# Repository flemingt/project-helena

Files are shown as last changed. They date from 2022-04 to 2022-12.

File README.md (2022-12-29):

# project-helena
Atari XL keyboard replacement

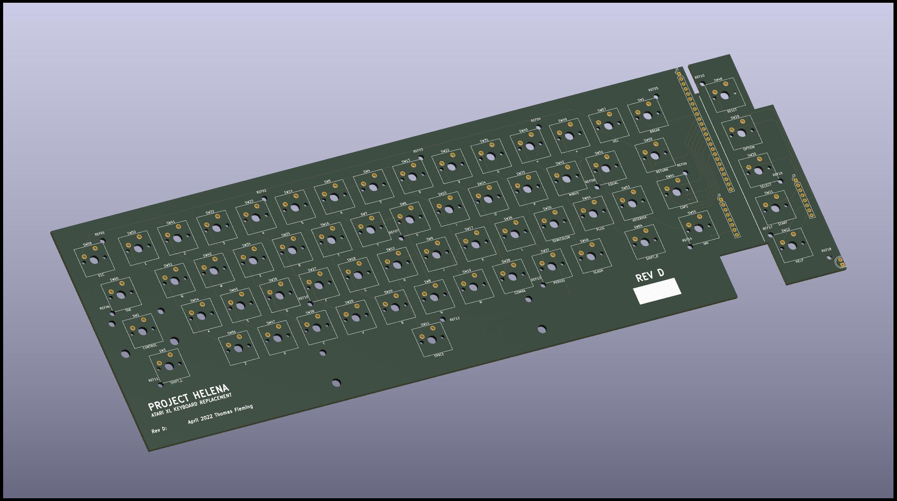
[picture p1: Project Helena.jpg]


What can go wrong with a bunch of switches? :)

Building on Ivop's project I've designed rev B, C, & D of the board.
Rev D has been designed with slightly different ribbon cable mounting points and moved the LED solder location to shorten the length of the board by a few mm. It is now ~111x346mm

The Helena Aux pcb plugs into the keyboard ribbon slot on the mainboard. For the 600XL 0.8mm seems to work, but 0.6mm or thinner is required for the 800XL.

I've added holes to make the switches PCB mount, some holes to mount stabilisers for the spacebar, and even more holes to align with the metal backplane of the original mylar / Stackpole keyboard of my 600XL. Maybe someone will need the mounting holes in the future. 

I've designed some 3D printed bracketry to use the screw posts in the top half of the case. Also some upper supports to minimise keyboard flex. These hook on to the PCB and the aluminium pieces that hold the cartridge doors.

I've designed cherry to Stackpole replacement stems for mechanical switches, but in the end I went for adaptors.

In addition, I've created a bracket to mount the U1MB expansion board. Note, you'll have to relocate the battery to make this all fit in the confines of a 600XL.

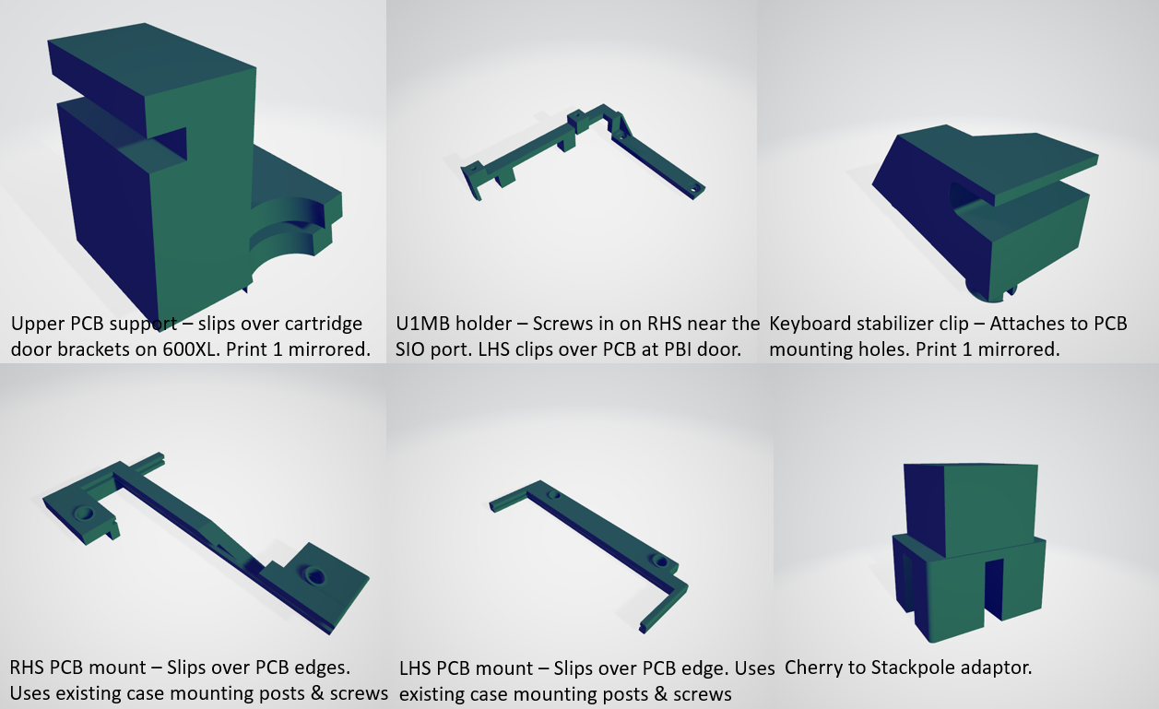
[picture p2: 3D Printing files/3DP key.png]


All the 3D printed parts use standard PLA, 50% infill. Some of the shapes area a bit tricky, but I've successfully printed everything with some thought on orientation and supports in the slicer.

Scorpio_NY on the Atariage forums has created 3D printable plates which will stiffen up the keyboard PCB and allow more accurate mounting on the switches. See the "Plate Files" directory. To accomodate the plates he's also developed new stabilizer files (in the "Final Stab Files" directory) and support brackets (in the "Final Support Bracket Files" directory).

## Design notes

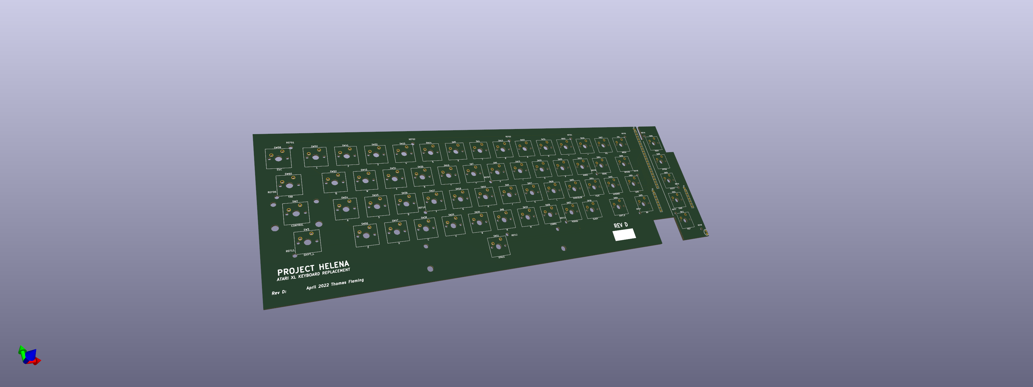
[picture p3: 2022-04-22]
kicad/Helena Main/Raytraced.png

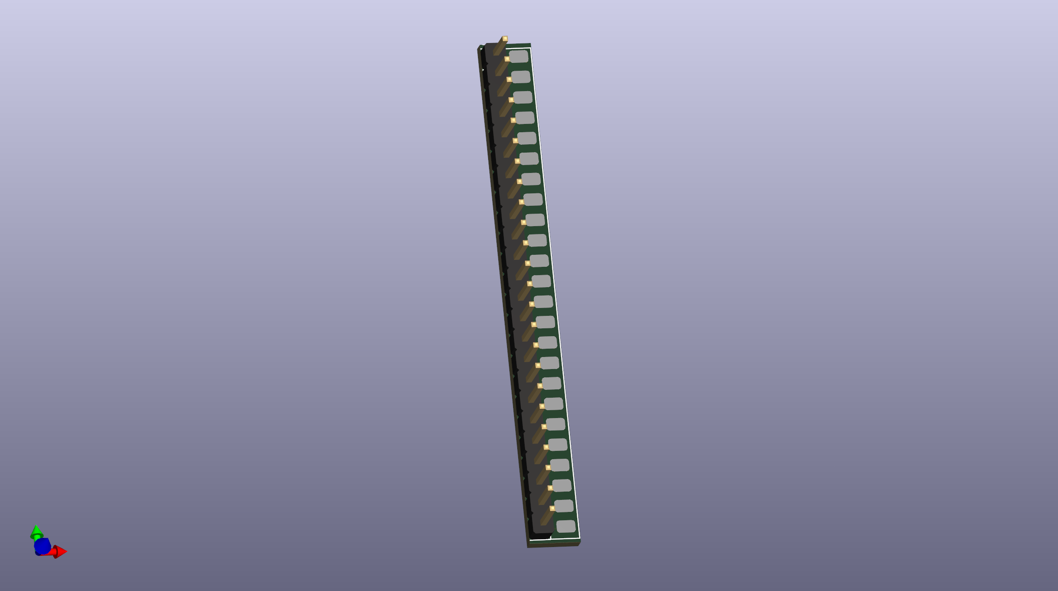
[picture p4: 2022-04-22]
kicad/Helena Aux/Raytraced.png

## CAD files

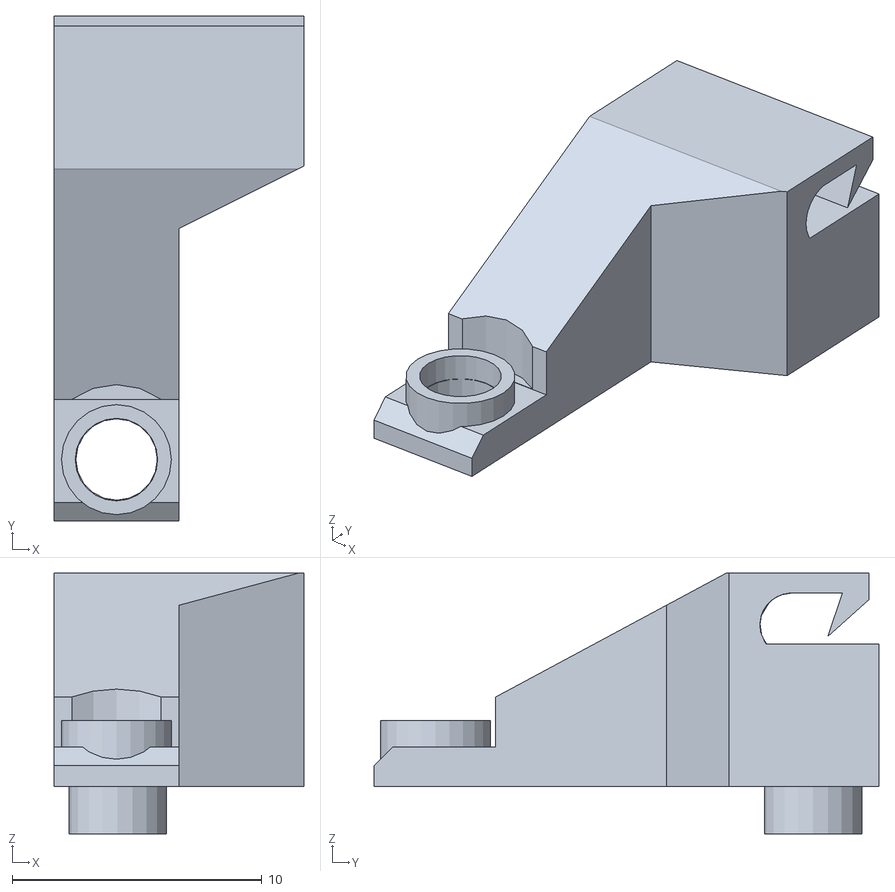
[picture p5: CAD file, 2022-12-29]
3D Printing files/Final Stab Files/PH Right Stab V 1.0 Final.stl
10.0 x 20.2 x 10.4

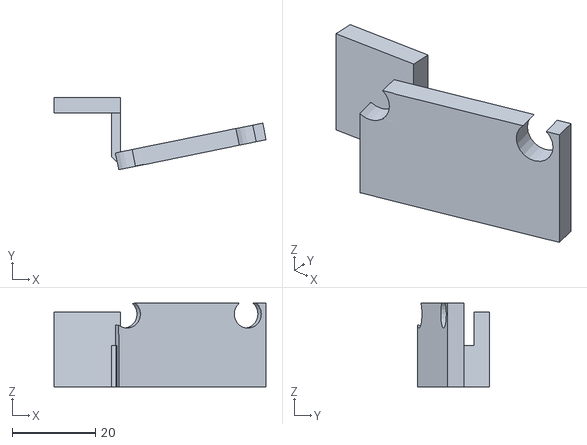
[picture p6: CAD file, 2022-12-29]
3D Printing files/Final Support Bracket Files/600XL/Project Helena 600XL Support Right v 1.0.stl
51.0 x 17.4 x 20.1

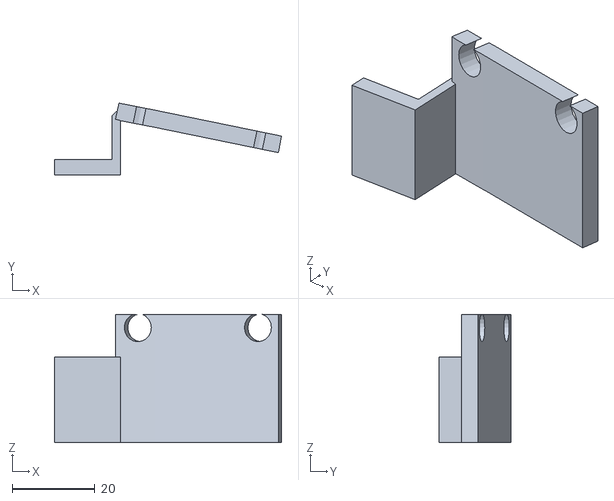
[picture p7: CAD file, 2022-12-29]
3D Printing files/Final Support Bracket Files/800XL/Project Helena Support 800XL Back Right v 1.0 (meshmixer).stl
54.9 x 17.4 x 31.0

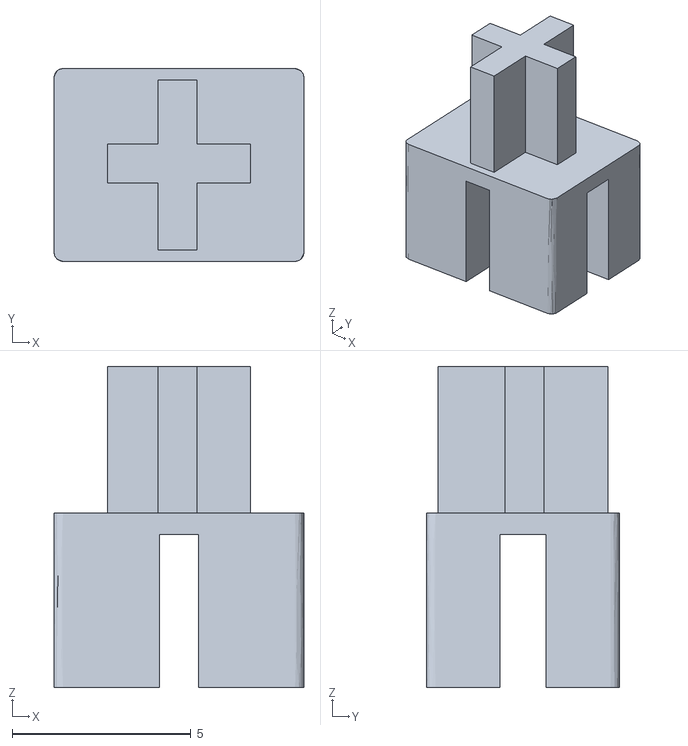
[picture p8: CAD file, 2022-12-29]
3D Printing files/MX to Futaba Final 1.0.stl
7.00 x 5.40 x 8.99

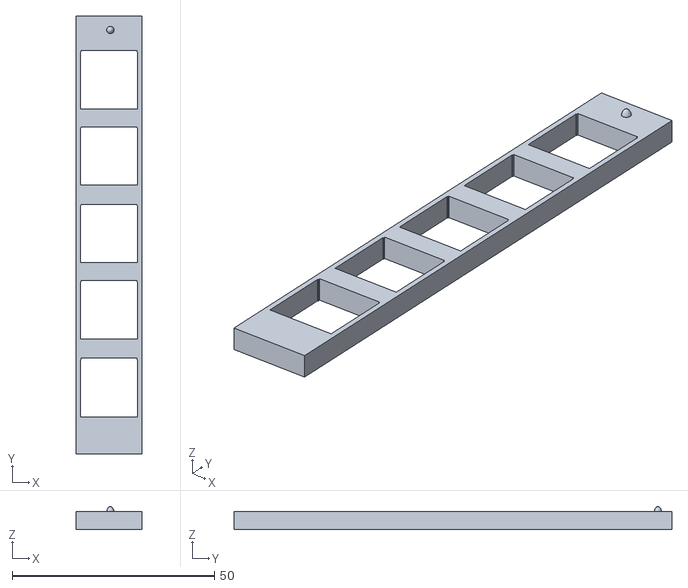
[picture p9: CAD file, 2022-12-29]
3D Printing files/Plate Files 1.0/Project Helena PCB_M.svg_4.5mm Function Keys v 1.0.stl
16.3 x 108.4 x 5.70

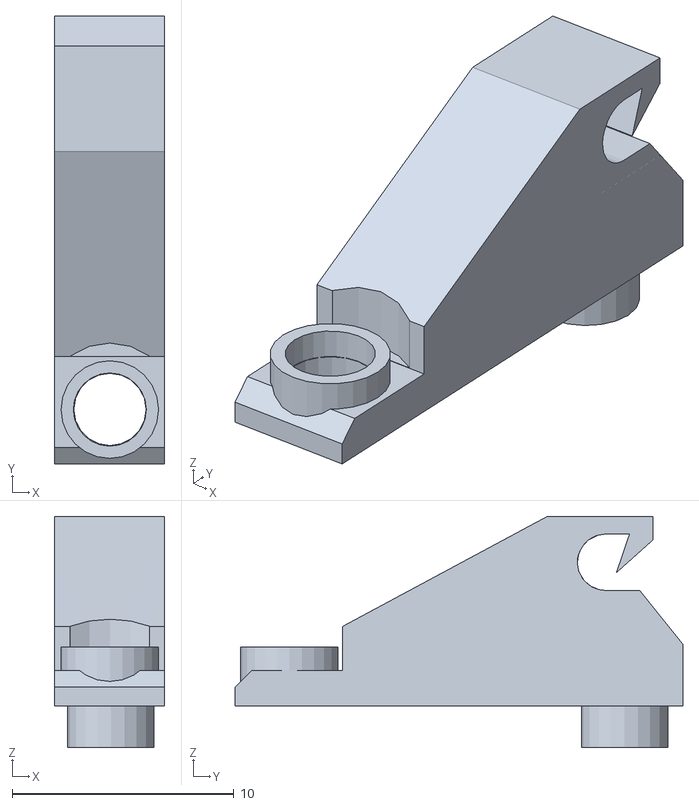
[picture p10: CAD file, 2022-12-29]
3D Printing files/Final Stab Files/Small Stab v 1.0.stl
4.97 x 20.2 x 10.4

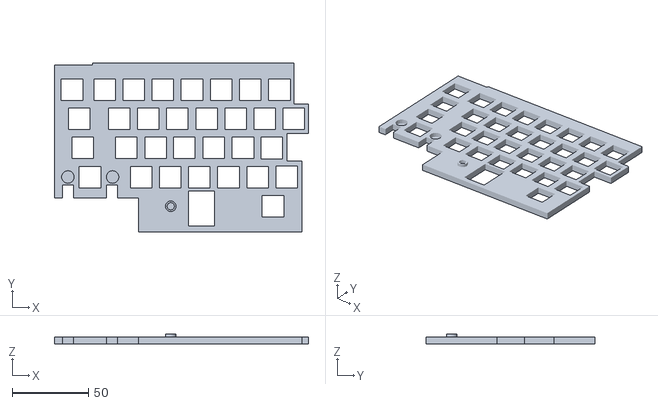
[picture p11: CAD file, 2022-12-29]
3D Printing files/Plate Files 1.0/Project Helena PCB_M.svg_4.5mm Left Half v 1.0 Final.stl
166.2 x 110.4 x 6.50

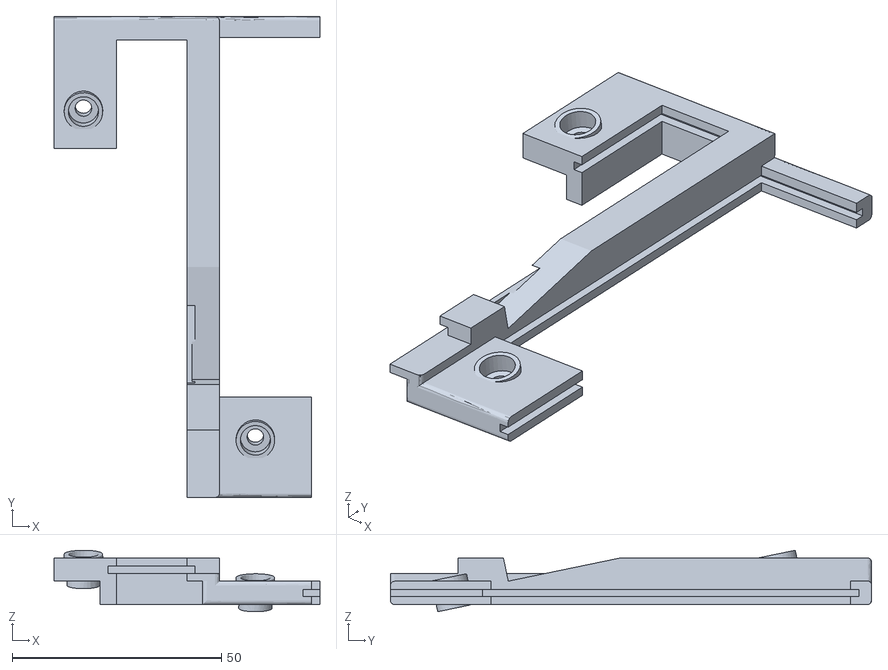
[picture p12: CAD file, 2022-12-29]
3D Printing files/RHS Final 800XL Remix.stl
63.5 x 115.0 x 14.7

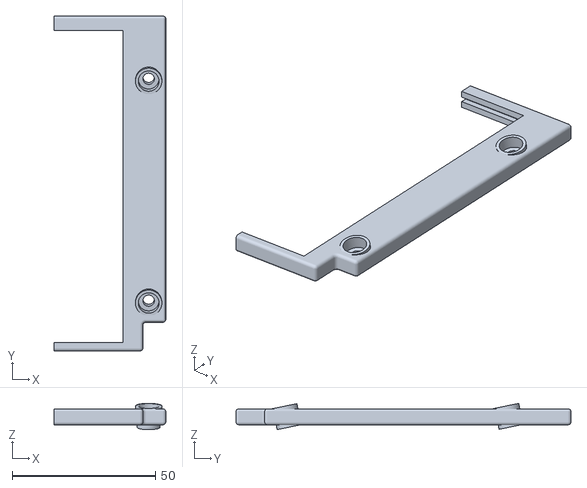
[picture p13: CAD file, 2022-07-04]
3D Printing files/LHS Final.stl
39.0 x 117.0 x 9.19

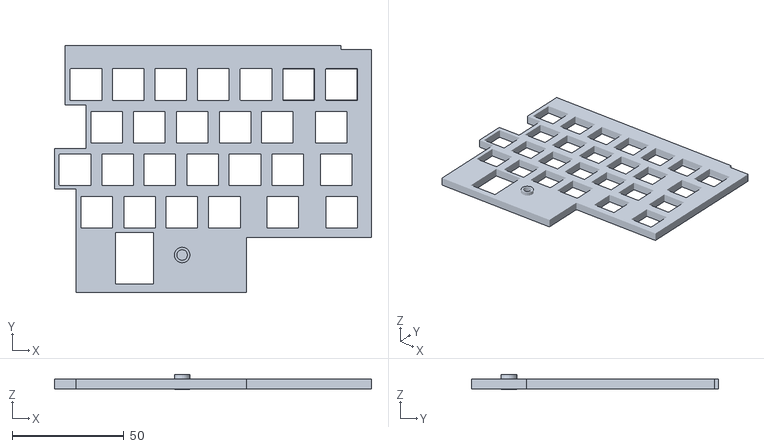
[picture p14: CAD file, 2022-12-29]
3D Printing files/Plate Files 1.0/Project Helena PCB_M.svg_4.5mm Right Half v 1.0 Final.stl
141.7 x 110.4 x 6.50

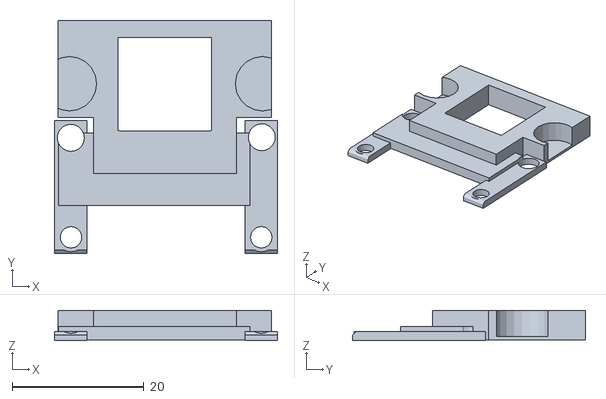
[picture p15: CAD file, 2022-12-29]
3D Printing files/Final Stab Files/Stab Hole Template v 1.0.stl
33.8 x 35.3 x 4.59

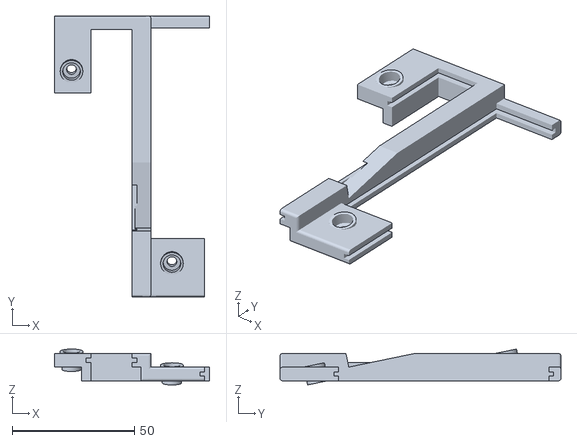
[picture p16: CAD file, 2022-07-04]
3D Printing files/RHS Final.stl
63.5 x 115.0 x 14.7

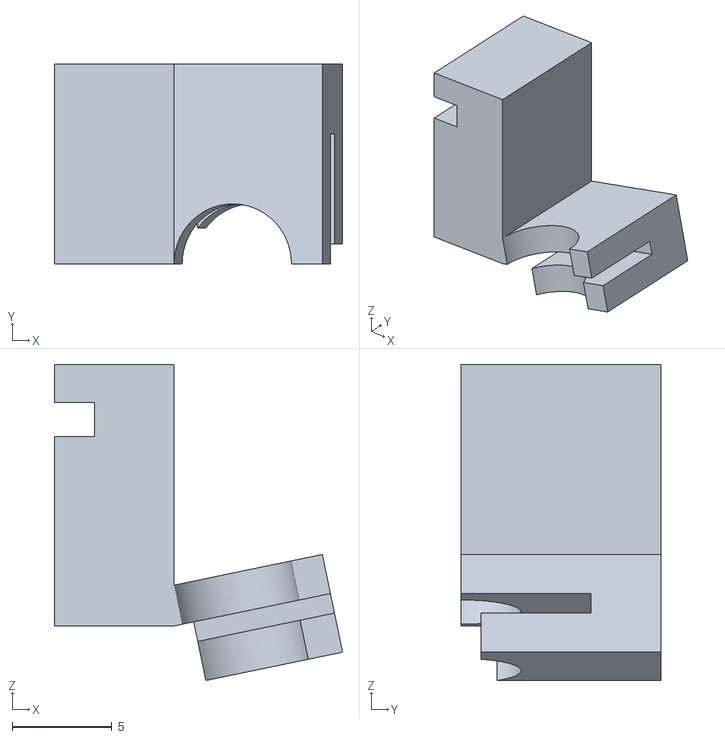
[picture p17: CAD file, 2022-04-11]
3D Printing files/upper support final.stl
14.4 x 10.0 x 15.8

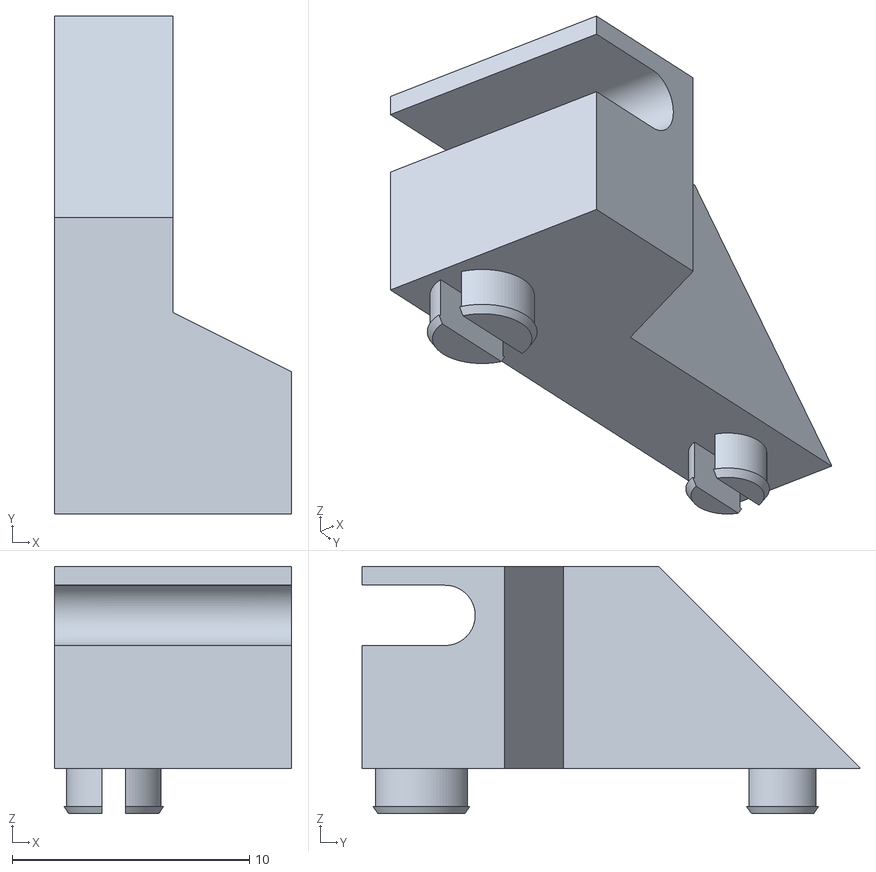
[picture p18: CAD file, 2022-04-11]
3D Printing files/Stab Final.stl
10.0 x 21.0 x 10.4

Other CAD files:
3D Printing files/Final Support Bracket Files/600XL/Project Helena 600XL Support Left v 1.0.stl
3D Printing files/Final Stab Files/PH Left Stab V.1.0 Final.stl
3D Printing files/U1MB near final.stl
3D Printing files/Cherry to stackpole Final.stl

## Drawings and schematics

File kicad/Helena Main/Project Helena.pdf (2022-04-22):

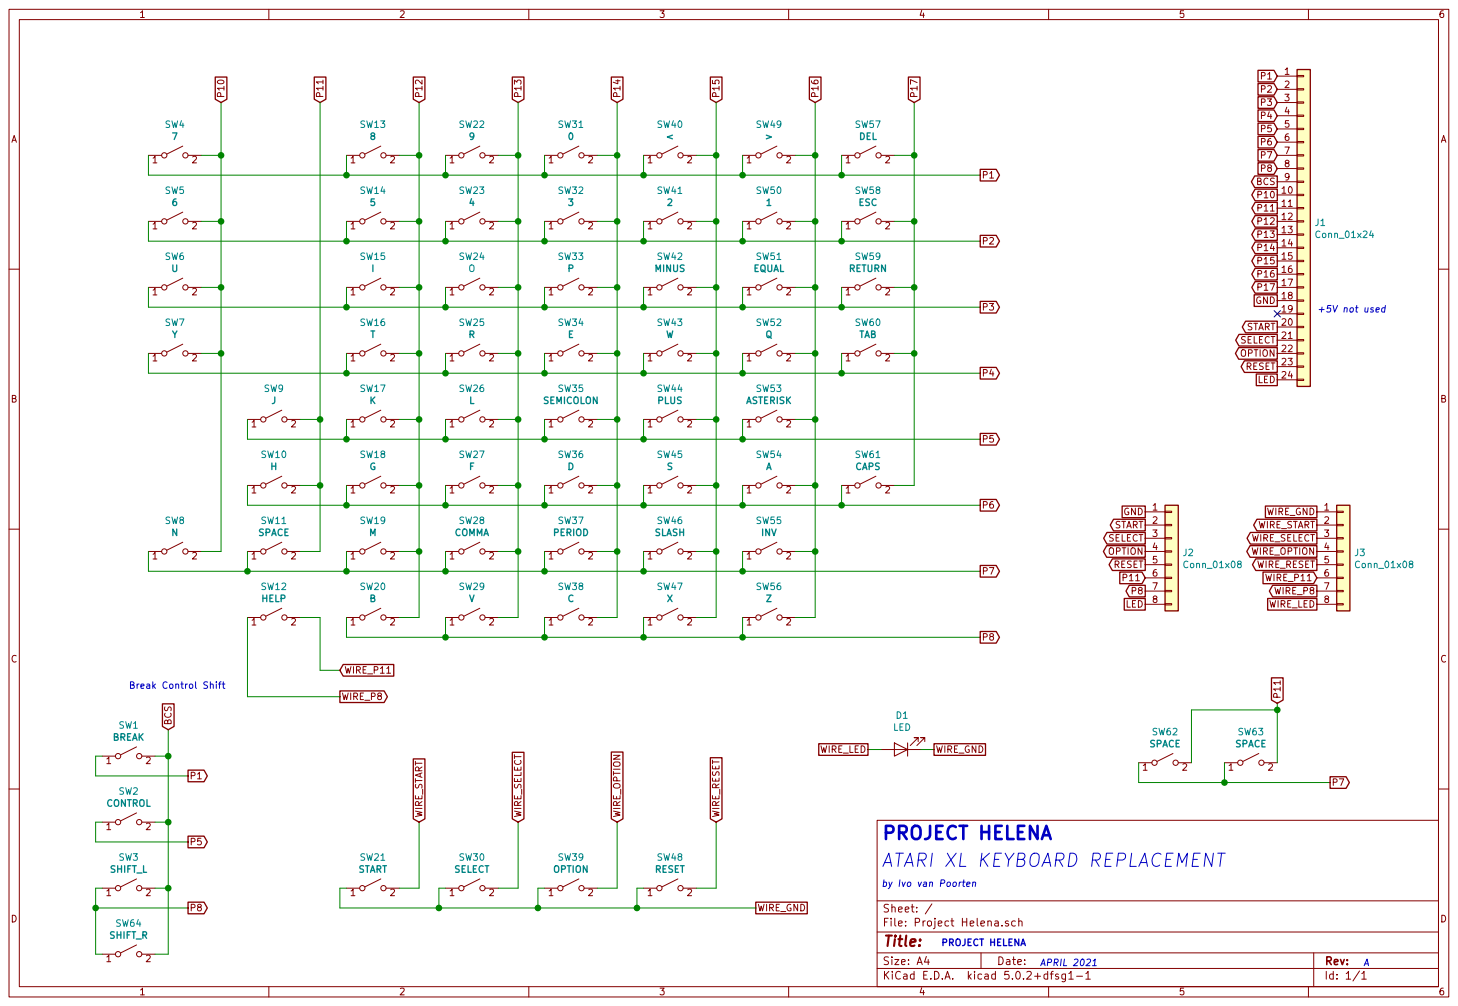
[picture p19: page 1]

+5V not used PROJECT HELENA

ATARI XL KEYBOARD REPLACEMENT

by Ivo van Poorten PROJECT HELENA

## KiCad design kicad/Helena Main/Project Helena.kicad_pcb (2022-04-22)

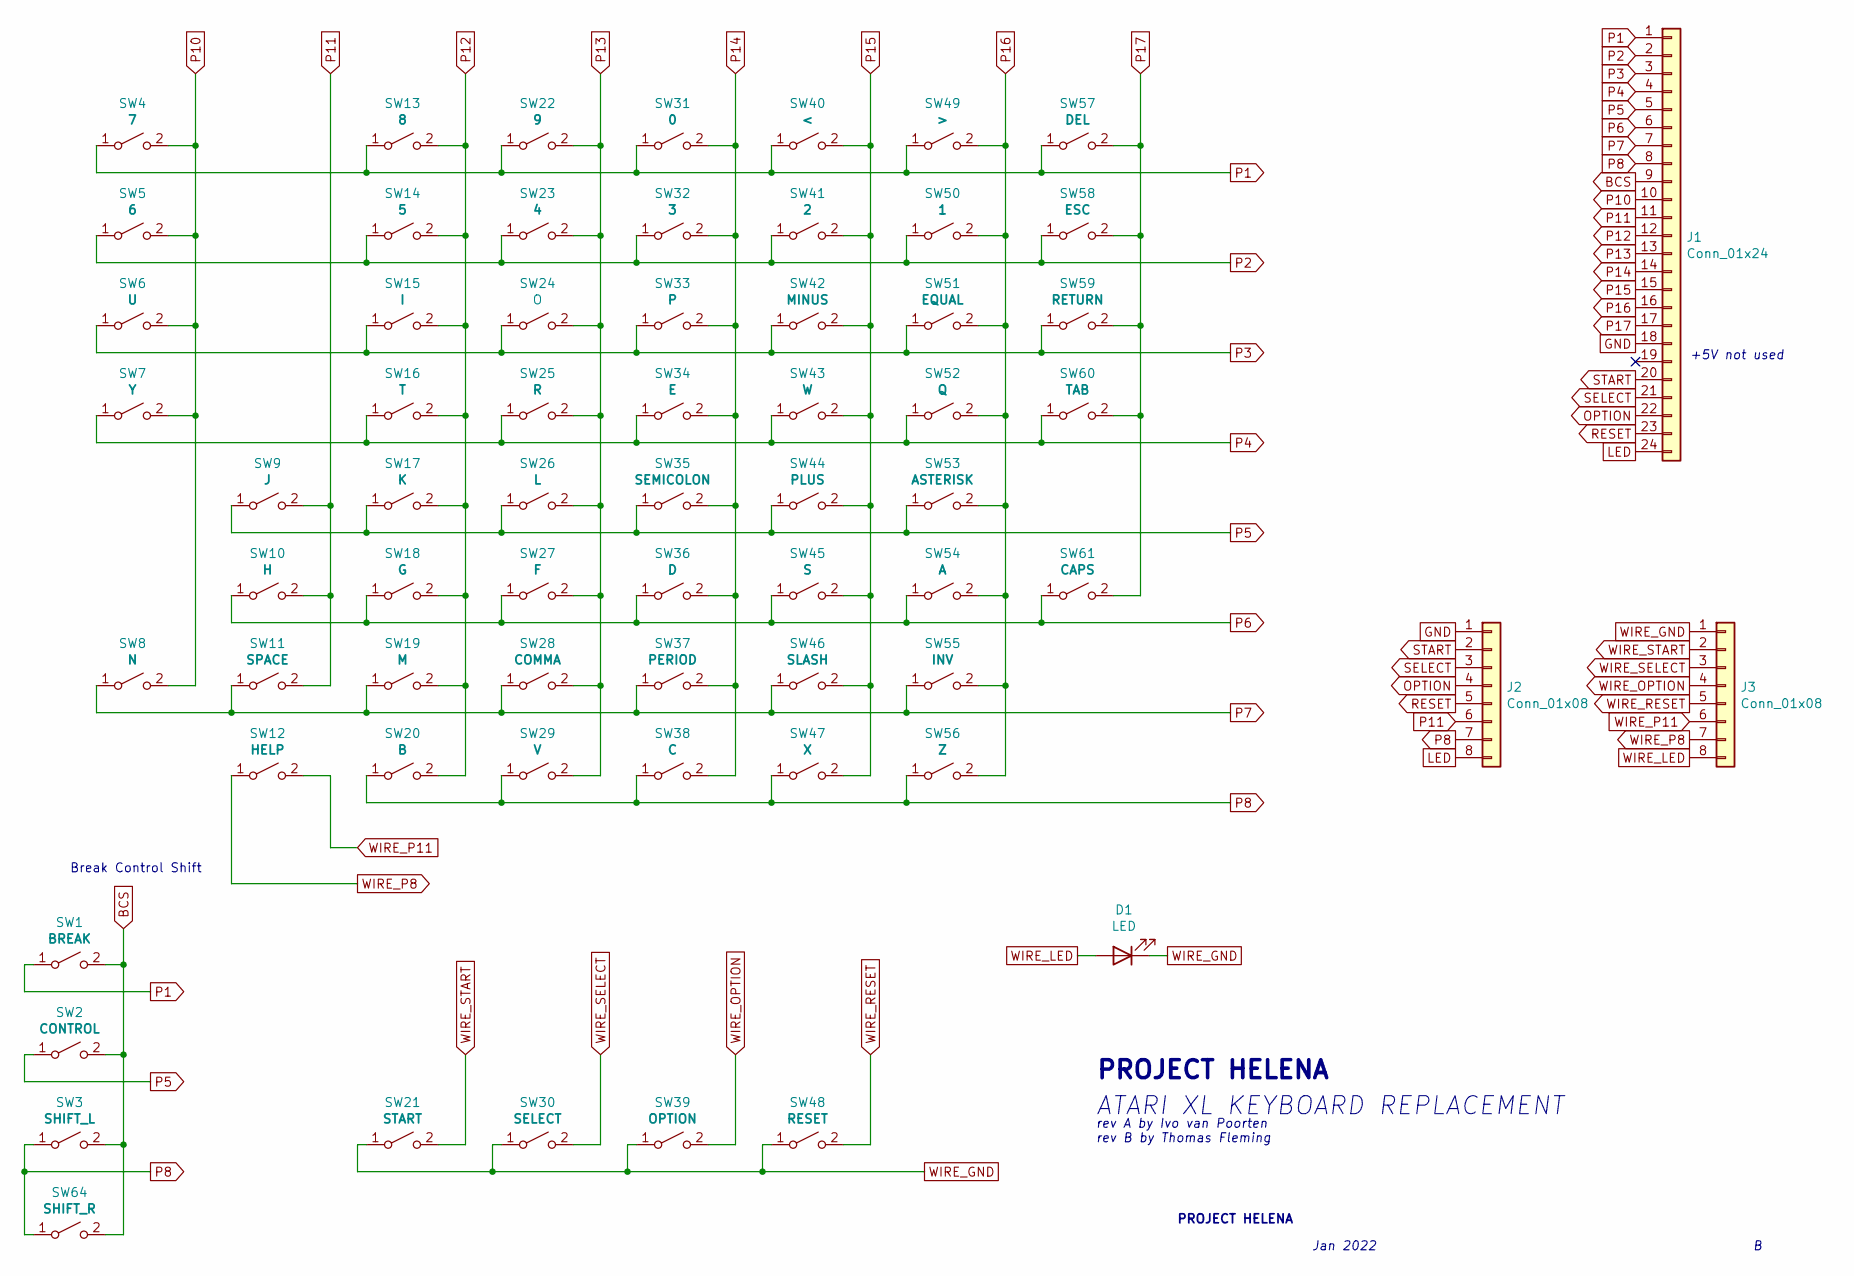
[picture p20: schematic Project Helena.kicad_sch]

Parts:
D1: LED; LED_D5.0mm
J1: Conn_01x24; PinHeader_1x24_P2.54mm_Vertical
J2, J3: Conn_01x08; PinHeader_1x08_P2.54mm_Vertical
SW1: BREAK; SW_Cherry_MX1A_1.00u_Plate
SW2: CONTROL; SW_Cherry_MX1A_2.00u_Plate
SW3: SHIFT_L; SW_Cherry_MX1A_1.50u_Plate
SW4: 7; SW_Cherry_MX1A_1.00u_Plate
SW5: 6; SW_Cherry_MX1A_1.00u_Plate
SW6: U; SW_Cherry_MX1A_1.00u_Plate
SW7: Y; SW_Cherry_MX1A_1.00u_Plate
SW8: N; SW_Cherry_MX1A_1.00u_Plate
SW9: J; SW_Cherry_MX1A_1.00u_Plate
SW10: H; SW_Cherry_MX1A_1.00u_Plate
SW11: SPACE; SW_Cherry_MX1A_1.00u_Plate
SW12: HELP; SW_Cherry_MX1A_1.00u_Plate
SW13: 8; SW_Cherry_MX1A_1.00u_Plate
SW14: 5; SW_Cherry_MX1A_1.00u_Plate
SW15: I; SW_Cherry_MX1A_1.00u_Plate
SW16: T; SW_Cherry_MX1A_1.00u_Plate
SW17: K; SW_Cherry_MX1A_1.00u_Plate
SW18: G; SW_Cherry_MX1A_1.00u_Plate
SW19: M; SW_Cherry_MX1A_1.00u_Plate
SW20: B; SW_Cherry_MX1A_1.00u_Plate
SW21: START; SW_Cherry_MX1A_1.00u_Plate
SW22: 9; SW_Cherry_MX1A_1.00u_Plate
SW23: 4; SW_Cherry_MX1A_1.00u_Plate
SW24: O; SW_Cherry_MX1A_1.00u_Plate
SW25: R; SW_Cherry_MX1A_1.00u_Plate
SW26: L; SW_Cherry_MX1A_1.00u_Plate
SW27: F; SW_Cherry_MX1A_1.00u_Plate
SW28: COMMA; SW_Cherry_MX1A_1.00u_Plate
SW29: V; SW_Cherry_MX1A_1.00u_Plate
SW30: SELECT; SW_Cherry_MX1A_1.00u_Plate
SW31: 0; SW_Cherry_MX1A_1.00u_Plate
SW32: 3; SW_Cherry_MX1A_1.00u_Plate
SW33: P; SW_Cherry_MX1A_1.00u_Plate
SW34: E; SW_Cherry_MX1A_1.00u_Plate
SW35: SEMICOLON; SW_Cherry_MX1A_1.00u_Plate
SW36: D; SW_Cherry_MX1A_1.00u_Plate
SW37: PERIOD; SW_Cherry_MX1A_1.00u_Plate
SW38: C; SW_Cherry_MX1A_1.00u_Plate
SW39: OPTION; SW_Cherry_MX1A_1.00u_Plate
SW40: <; SW_Cherry_MX1A_1.00u_Plate
SW41: 2; SW_Cherry_MX1A_1.00u_Plate
SW42: MINUS; SW_Cherry_MX1A_1.00u_Plate
SW43: W; SW_Cherry_MX1A_1.00u_Plate
SW44: PLUS; SW_Cherry_MX1A_1.00u_Plate
SW45: S; SW_Cherry_MX1A_1.00u_Plate
SW46: SLASH; SW_Cherry_MX1A_1.00u_Plate
SW47: X; SW_Cherry_MX1A_1.00u_Plate
SW48: RESET; SW_Cherry_MX1A_1.00u_Plate
SW49: >; SW_Cherry_MX1A_1.00u_Plate
SW50: 1; SW_Cherry_MX1A_1.00u_Plate
SW51: EQUAL; SW_Cherry_MX1A_1.00u_Plate
SW52: Q; SW_Cherry_MX1A_1.00u_Plate
SW53: ASTERISK; SW_Cherry_MX1A_1.00u_Plate
SW54: A; SW_Cherry_MX1A_1.00u_Plate
SW55: INV; SW_Cherry_MX1A_1.00u_Plate
SW56: Z; SW_Cherry_MX1A_1.00u_Plate
SW57: DEL; SW_Cherry_MX1A_1.00u_Plate
SW58: ESC; SW_Cherry_MX1A_1.25u_Plate
SW59: RETURN; SW_Cherry_MX1A_1.50u_Plate
SW60: TAB; SW_Cherry_MX1A_1.75u_Plate
SW61: CAPS; SW_Cherry_MX1A_1.25u_Plate
SW64: SHIFT_R; SW_Cherry_MX1A_1.75u_Plate

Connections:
BCS: J1.9, SW1.2 (B), SW2.2 (B), SW3.2 (B), SW64.2 (B)
GND: J1.18, J2.1
LED: J1.24, J2.8
OPTION: J1.22, J2.4
P1: J1.1, SW1.1 (A), SW4.1 (A), SW13.1 (A), SW22.1 (A), SW31.1 (A), SW40.1 (A), SW49.1 (A), SW57.1 (A)
P2: J1.2, SW5.1 (A), SW14.1 (A), SW23.1 (A), SW32.1 (A), SW41.1 (A), SW50.1 (A), SW58.1 (A)
P3: J1.3, SW6.1 (A), SW15.1 (A), SW24.1 (A), SW33.1 (A), SW42.1 (A), SW51.1 (A), SW59.1 (A)
P4: J1.4, SW7.1 (A), SW16.1 (A), SW25.1 (A), SW34.1 (A), SW43.1 (A), SW52.1 (A), SW60.1 (A)
P5: J1.5, SW2.1 (A), SW9.1 (A), SW17.1 (A), SW26.1 (A), SW35.1 (A), SW44.1 (A), SW53.1 (A)
P6: J1.6, SW10.1 (A), SW18.1 (A), SW27.1 (A), SW36.1 (A), SW45.1 (A), SW54.1 (A), SW61.1 (A)
P7: J1.7, SW8.1 (A), SW11.1 (A), SW19.1 (A), SW28.1 (A), SW37.1 (A), SW46.1 (A), SW55.1 (A)
P8: J1.8, J2.7, SW3.1 (A), SW20.1 (A), SW29.1 (A), SW38.1 (A), SW47.1 (A), SW56.1 (A), SW64.1 (A)
P10: J1.10, SW4.2 (B), SW5.2 (B), SW6.2 (B), SW7.2 (B), SW8.2 (B)
P11: J1.11, J2.6, SW9.2 (B), SW10.2 (B), SW11.2 (B)
P12: J1.12, SW13.2 (B), SW14.2 (B), SW15.2 (B), SW16.2 (B), SW17.2 (B), SW18.2 (B), SW19.2 (B), SW20.2 (B)
P13: J1.13, SW22.2 (B), SW23.2 (B), SW24.2 (B), SW25.2 (B), SW26.2 (B), SW27.2 (B), SW28.2 (B), SW29.2 (B)
P14: J1.14, SW31.2 (B), SW32.2 (B), SW33.2 (B), SW34.2 (B), SW35.2 (B), SW36.2 (B), SW37.2 (B), SW38.2 (B)
P15: J1.15, SW40.2 (B), SW41.2 (B), SW42.2 (B), SW43.2 (B), SW44.2 (B), SW45.2 (B), SW46.2 (B), SW47.2 (B)
P16: J1.16, SW49.2 (B), SW50.2 (B), SW51.2 (B), SW52.2 (B), SW53.2 (B), SW54.2 (B), SW55.2 (B), SW56.2 (B)
P17: J1.17, SW57.2 (B), SW58.2 (B), SW59.2 (B), SW60.2 (B), SW61.2 (B)
RESET: J1.23, J2.5
SELECT: J1.21, J2.3
START: J1.20, J2.2
WIRE_GND: D1.1 (K), J3.1, SW21.1 (A), SW30.1 (A), SW39.1 (A), SW48.1 (A)
WIRE_LED: D1.2 (A), J3.8
WIRE_OPTION: J3.4, SW39.2 (B)
WIRE_P8: J3.7, SW12.1 (A)
WIRE_P11: J3.6, SW12.2 (B)
WIRE_RESET: J3.5, SW48.2 (B)
WIRE_SELECT: J3.3, SW30.2 (B)
WIRE_START: J3.2, SW21.2 (B)

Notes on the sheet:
+5V not used
Break Control Shift
rev A by Ivo van Poorten rev B by Thomas Fleming
ATARI XL KEYBOARD REPLACEMENT
Jan 2022
PROJECT HELENA

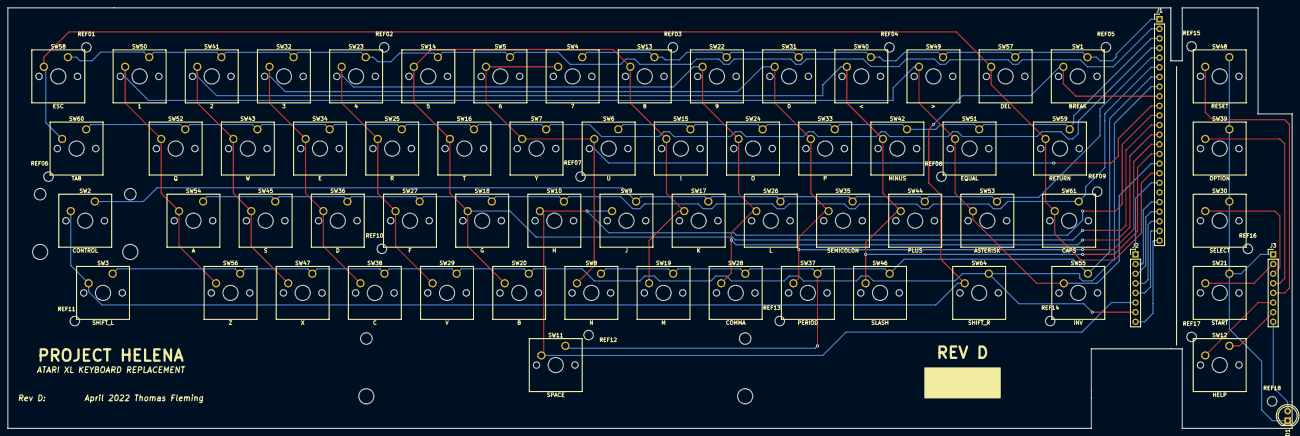
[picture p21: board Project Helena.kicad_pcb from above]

Board: 2 copper layers, 339.0 x 111.0 mm, 84 parts (0 on the bottom side), 31 nets.

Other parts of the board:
REF01, REF02, REF03, REF04, REF05, REF06, REF07, REF08, REF09, REF10, REF11, REF12, REF13, REF14, REF15, REF16, REF17, REF18: MountingHole_2.5mm

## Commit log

2022-01-27 Created Rev B
    Rev B of ivops Atari600xl keyboard.
    Modified switch footprints to accommodate 5 holes for stability.
    Added PCB mount stabilizer holes for 3D printed brackets.
    Added through-holes to match the metal backplate on my membrane 600xl keyboard with the intention of making stand-offs.
    Extensively rerouted traces to avoid all the new holes.
    [Cherry to Stackpool v1.stl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]
2022-01-28 adding 3D printing file/folder
    adding folder for 3D printing and rev 1 of cherry to stackpole stem replacement
    [cherry to stackpole replacement stem.stl]
2022-02-01 cherry / Gateron to stackpole replacement stem v2
    Version 2 with longer Stackpole section to accommodate keypress full travel
    [cherry to stackpole replacement stem v2.stl]
2022-02-02 cherry / Gateron to stackpole replacement stem v3
    Redrew CAD from scratch and added some stabilising features
    [cherry to stackpole replacement stem v3.stl]
2022-02-05 Add files via upload
    raised wings by 0.75mm and narrowed each by 0.5mm
    [cherry to stackpole replacement stem v4.stl]
2022-03-18 Add files via upload
    Updated PCB to rev C. Moved backplane holes for better alignment. Moved main connector to prevent ribbon cable overlap with daughterboard.
    [Project Helena.kicad_pcb]
2022-03-19 Update README.md
    updated to reflect current status of rev C
2022-03-20 Delete cherry to stackpole replacement stem v2.stl
    Version 4 is better
    [cherry to stackpole replacement stem v2.stl]
2022-03-20 Delete cherry to stackpole replacement stem v3.stl
    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
    [cherry to stackpole replacement stem v3.stl]
2022-03-20 Delete cherry to stackpole replacement stem.stl
    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
    [cherry to stackpole replacement stem.stl]
2022-03-20 Left hand side keyboard PCB mount
    [LHS keyboard mount V2.stl]
2022-04-03 Delete LHS keyboard mount V2.stl
    replacing with near final version
    [LHS keyboard mount V2.stl]
2022-04-03 Add files via upload
    near final keyboard mounting brackets. Z may need some tweaking
    [LHS keyboard mount V5.stl, middle keyboard mount V6.stl]
2022-04-03 Add files via upload
    Ultimate 1MB holder designed to go under the new keyboard. Note desolder and relocate the battery.
    [U1MB holder v3.stl]
2022-04-03 Update README.md
    updating to reflect current status.
2022-04-11 Adding near final versions of 3D printable files
    [Cherry to stackpole Final.stl, LHS Final.stl, RHS Final.stl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]
2022-04-22 Delete kicad directory
    preparing for rev D
    [Project Helena-B.Cu.gbr, Project Helena-B.Mask.gbr, Project Helena-B.SilkS.gbr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]
2022-04-22 Add files via upload
    Updating main PCB to rev D: shorter with better placement of power LED.
    Creating rev A of Aux PCB to interface with the existing mylar connector.
    [Helena Aux-B_Cu.gbr, Helena Aux-B_Mask.gbr, Helena Aux-B_Paste.gbr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]
2022-04-22 Delete Other resources directory
    no longer required
    [Cherry to Stackpool v1.stl, kcadapt2-stackpole-v4.obj, main holes.dxf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]
2022-06-17 Retrying Gerber uploads of rev D
    [Project Helena-B_Cu.gbr, Project Helena-B_Mask.gbr, Project Helena-B_Silkscreen.gbr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]
2022-07-04 Add files via upload
    Widening screw holes for 800xl.
    Adding extra slot for option key PCB fitment.
    [LHS Final.stl, RHS Final.stl]
2022-12-29 Add files via upload
    Scorpio_NY files
    [MX to Futaba Final 1.0.stl, RHS Final 800XL Remix.stl]
